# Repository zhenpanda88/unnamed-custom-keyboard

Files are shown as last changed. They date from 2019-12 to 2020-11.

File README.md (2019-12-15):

# untitled-keyboard-project
Unnamed custom mechanical keyboard project. I might finish this one day. It'll probably be a split layout. But eh...

Project Roadmap:
- V.0: Simple layout prototype for minimal functionality and software testing (probably 40%-size amount of keys)
- V.1: Ergonomic form layout and bigger layout (60%+ or 40% with different layers)
- V.2+: Bluetooth support, different layouts, on board LED display, backlighting (stretch goal, I doubt I will get this far lol)

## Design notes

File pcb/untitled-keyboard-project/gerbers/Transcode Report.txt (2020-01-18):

   ---- Transcoding 'C:\Users\White\AppData\Local\Temp\untitled-keyboard-project gerbers_importZIP\untitled-keyboard-project-F_Paste.gtp' ----   Thu Jan 02 16:57:49 2020

D10   --> D100
D12   --> D101
-----------------------------------------------------------------

   ---- Transcoding 'C:\Users\White\AppData\Local\Temp\untitled-keyboard-project gerbers_importZIP\untitled-keyboard-project-F_Cu.gtl' ----   Thu Jan 02 16:57:49 2020

D10   --> D102
D11   --> D103
D13   --> D104
D14   --> D105
D15   --> D106
D16   --> D107
D17   --> D108
-----------------------------------------------------------------

   ---- Transcoding 'C:\Users\White\AppData\Local\Temp\untitled-keyboard-project gerbers_importZIP\untitled-keyboard-project-Edge_Cuts.gml' ----   Thu Jan 02 16:57:49 2020

D10   --> D109
-----------------------------------------------------------------

   ---- Transcoding 'C:\Users\White\AppData\Local\Temp\untitled-keyboard-project gerbers_importZIP\untitled-keyboard-project-B_Cu.gbl' ----   Thu Jan 02 16:57:49 2020

D10   --> D110
D11   --> D111
D12   --> D112
D14   --> D113
D15   --> D114
D16   --> D115
D17   --> D116
-----------------------------------------------------------------

   ---- Transcoding 'C:\Users\White\AppData\Local\Temp\untitled-keyboard-project gerbers_importZIP\untitled-keyboard-project-B_Paste.gbp' ----   Thu Jan 02 16:57:49 2020

D11   --> D117
-----------------------------------------------------------------

   ---- Transcoding 'C:\Users\White\AppData\Local\Temp\untitled-keyboard-project gerbers_importZIP\untitled-keyboard-project-B_SilkS.gbo' ----   Thu Jan 02 16:57:49 2020

D10   --> D118
D11   --> D119
-----------------------------------------------------------------

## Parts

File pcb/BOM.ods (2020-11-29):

Ref | Component | Source | Ordered
U1 | ATmega32U4 | https://www.digikey.com/product-detail/en/microchip-technology/ATMEGA32U4RC-AU/ATMEGA32U4RC-AU-ND/2507982 | Y
J1 | MiniUSB | https://www.digikey.com/product-detail/en/edac-inc/690-005-299-043/151-1206-1-ND/4312192 | Y
J2 | 3.5mm TRRS Conn | https://www.amazon.com/Female-Connector-Stereo-Headphone-PJ320E/dp/B07SC79NWH | Y
C1, C2 | 18pF | https://www.digikey.com/product-detail/en/yageo/CC0805JRNPO9BN180/311-1102-1-ND/303012 | Y
C3 | 4.7pF | https://www.digikey.com/product-detail/en/kemet/C0805C479D5GACTU/399-9252-1-ND/3522770 | Y
C4, C5, C6, C7 | 0.1uF | https://www.digikey.com/product-detail/en/kemet/C0805C104Z5VACTU/399-1177-1-ND/411452 | Y
C8 | 1uF | https://www.digikey.com/product-detail/en/kemet/C0805C105Z4VACTU/399-8011-1-ND/3471734 | Y
R1, R2 | 10kOhm | https://www.digikey.com/product-detail/en/yageo/RC0805FR-0710KL/311-10.0KCRCT-ND/730482 | Y
R3, R4 | 22Ohm | https://www.digikey.com/product-detail/en/te-connectivity-passive-product/CRGCQ0805J22R/A130124CT-ND/8577956 | Y
SW1 | Reset Push Button | https://www.digikey.com/product-detail/en/e-switch/TL3342F160QG-TR/EG2531CT-ND/379004 | Y
X1 | Crystal 16MHz | https://www.digikey.com/product-detail/en/epson/FA-238-16.0000MB-C3/SER3686CT-ND/2403459 | Y
D1-24 | Diode | https://www.digikey.com/product-detail/en/taiwan-semiconductor-corporation/TS4148C-RZG/TS4148CRZGCT-ND/7359812 | Y

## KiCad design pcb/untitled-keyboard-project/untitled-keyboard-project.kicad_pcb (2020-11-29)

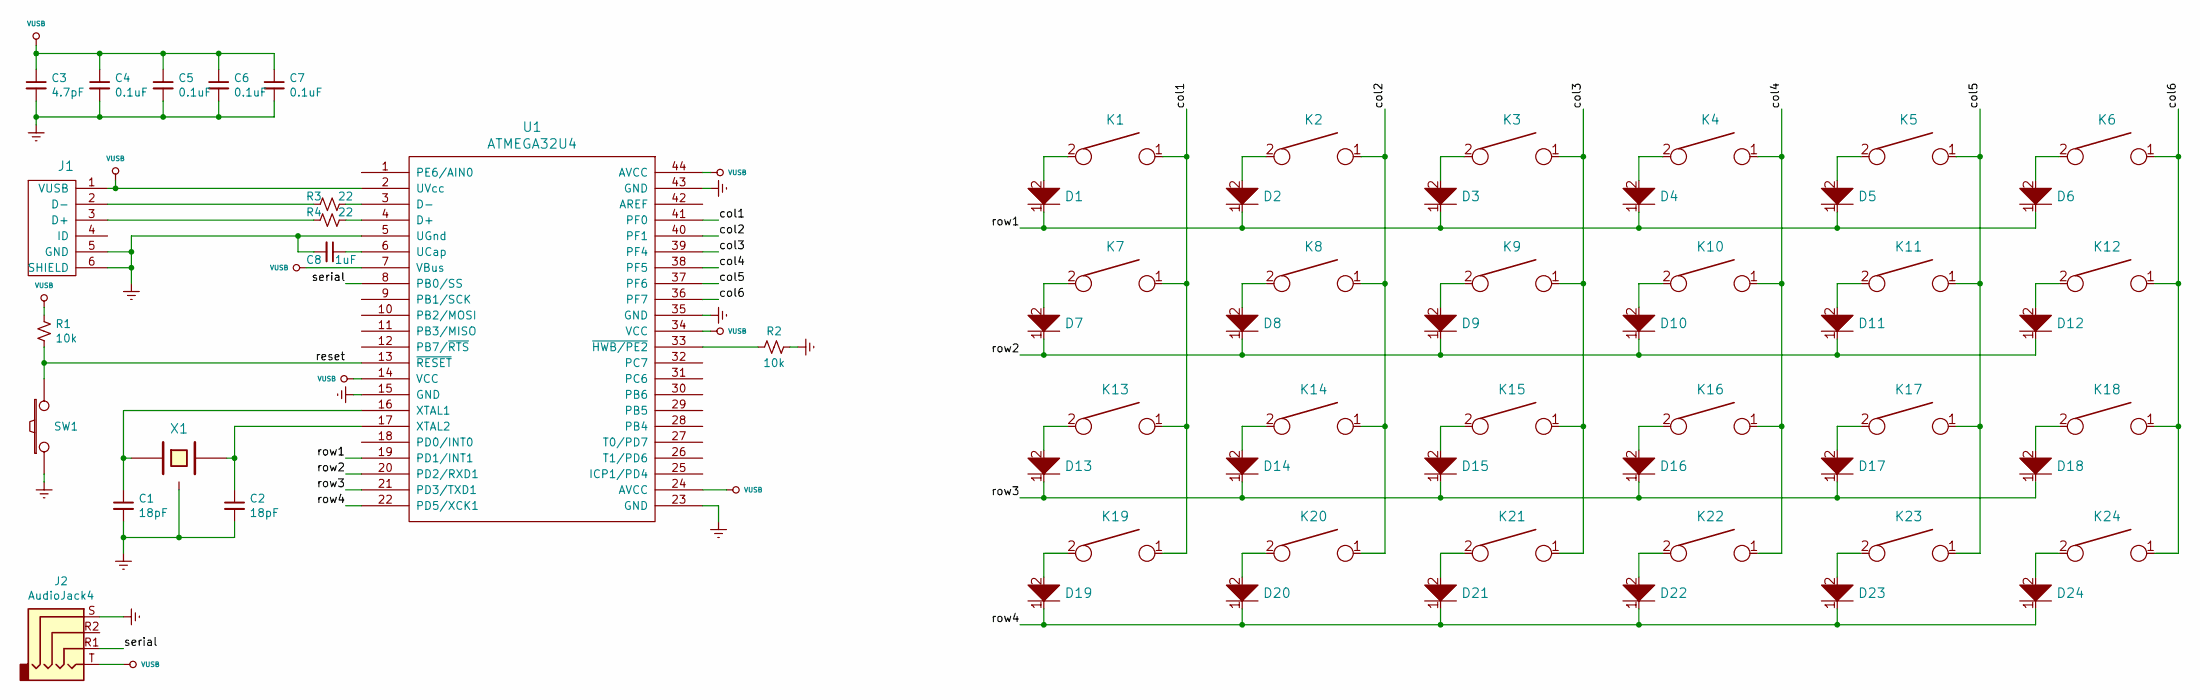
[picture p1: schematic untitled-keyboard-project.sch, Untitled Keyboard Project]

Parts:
C1, C2: 18pF; C_0805_2012Metric
C3: 4.7pF; C_0805_2012Metric
C4, C5, C6, C7: 0.1uF; C_0805_2012Metric
C8: 1uF; C_0805_2012Metric
D1, D2, D3, D4, D5, D6, D7, D8, D9, D10, D11, D12, D13, D14, D15, D16, D17, D18, D19, D20, D21, D22, D23, D24: D; D_0603_1608Metric
J1: USB_mini_micro_B; USB_Micro-B_Molex-105017-0001
J2: AudioJack4; Jack_3.5mm_PJ320E_Horizontal
K1, K2, K3, K4, K5, K6, K7, K8, K9, K10, K11, K12, K13, K14, K15, K16, K17, K18, K19, K20, K21, K22, K23, K24: KEYSW; SW_Cherry_MX_1.00u_PCB
R1, R2: 10k; R_0805_2012Metric
R3, R4: 22; R_0805_2012Metric
SW1: SW_PUSH; SW_SPST_TL3342
U1: ATMEGA32U4; TQFP-44_10x10mm_P0.8mm
X1: XTAL_GND; Crystal_SMD_TXC_7M-4Pin_3.2x2.5mm

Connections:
/col1: K1.1, K7.1, K13.1, K19.1, U1.41 (PF0)
/col2: K2.1, K8.1, K14.1, K20.1, U1.40 (PF1)
/col3: K3.1, K9.1, K15.1, K21.1, U1.39 (PF4)
/col4: K4.1, K10.1, K16.1, K22.1, U1.38 (PF5)
/col5: K5.1, K11.1, K17.1, K23.1, U1.37 (PF6)
/col6: K6.1, K12.1, K18.1, K24.1, U1.36 (PF7)
/reset: R1.1, SW1.2, U1.13 (~RESET)
/row1: D1.1, D2.1, D3.1, D4.1, D5.1, D6.1, U1.19 (PD1/INT1)
/row2: D7.1, D8.1, D9.1, D10.1, D11.1, D12.1, U1.20 (PD2/RXD1)
/row3: D13.1, D14.1, D15.1, D16.1, D17.1, D18.1, U1.21 (PD3/TXD1)
/row4: D19.1, D20.1, D21.1, D22.1, D23.1, D24.1, U1.22 (PD5/XCK1)
/serial: J2.R1, U1.8 (PB0/SS)
GNDREF: C1.2, C2.2, C3.2, C4.2, C5.2, C6.2, C7.2, C8.2, J1.5 (GND), J1.6 (SHIELD), J2.S, R2.2, SW1.1, U1.5 (UGnd), U1.15 (GND), U1.23 (GND), U1.35 (GND), U1.43 (GND), X1.2, X1.4
unnamed: C1.1, U1.16 (XTAL1), X1.1
unnamed: C2.1, U1.17 (XTAL2), X1.3
unnamed: C8.1, U1.6 (UCap)
unnamed: D1.2, K1.2
unnamed: D2.2, K2.2
unnamed: D3.2, K3.2
unnamed: D4.2, K4.2
unnamed: D5.2, K5.2
unnamed: D6.2, K6.2
unnamed: D7.2, K7.2
unnamed: D8.2, K8.2
unnamed: D9.2, K9.2
unnamed: D10.2, K10.2
unnamed: D11.2, K11.2
unnamed: D12.2, K12.2
unnamed: D13.2, K13.2
unnamed: D14.2, K14.2
unnamed: D15.2, K15.2
unnamed: D16.2, K16.2
unnamed: D17.2, K17.2
unnamed: D18.2, K18.2
unnamed: D19.2, K19.2
unnamed: D20.2, K20.2
unnamed: D21.2, K21.2
unnamed: D22.2, K22.2
unnamed: D23.2, K23.2
unnamed: D24.2, K24.2
unnamed: J1.2 (D-), R3.1
unnamed: J1.3 (D+), R4.1
unnamed: R2.1, U1.33 (~HWB/PE2)
unnamed: R3.2, U1.3 (D-)
unnamed: R4.2, U1.4 (D+)
VUSB: C3.1, C4.1, C5.1, C6.1, C7.1, J1.1 (VUSB), J2.T, R1.2, U1.2 (UVcc), U1.7 (VBus), U1.14 (VCC), U1.24 (AVCC), U1.34 (VCC), U1.44 (AVCC)

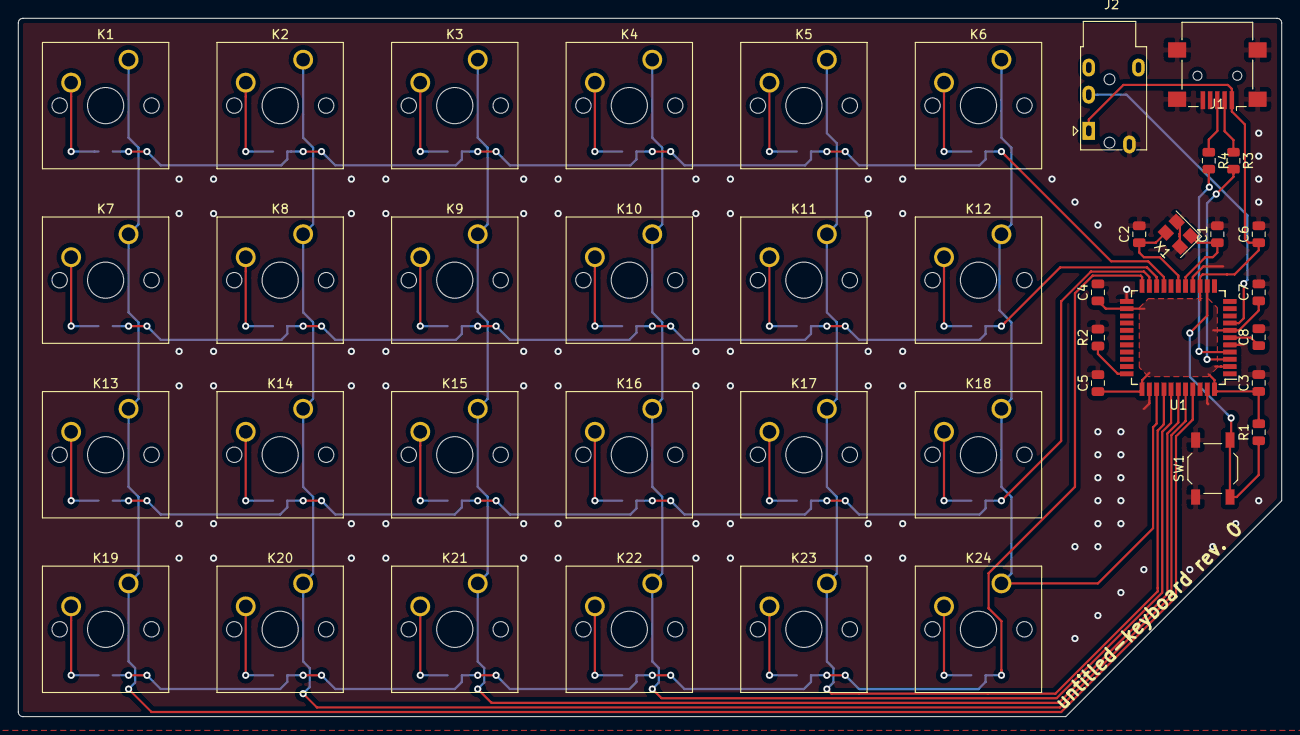
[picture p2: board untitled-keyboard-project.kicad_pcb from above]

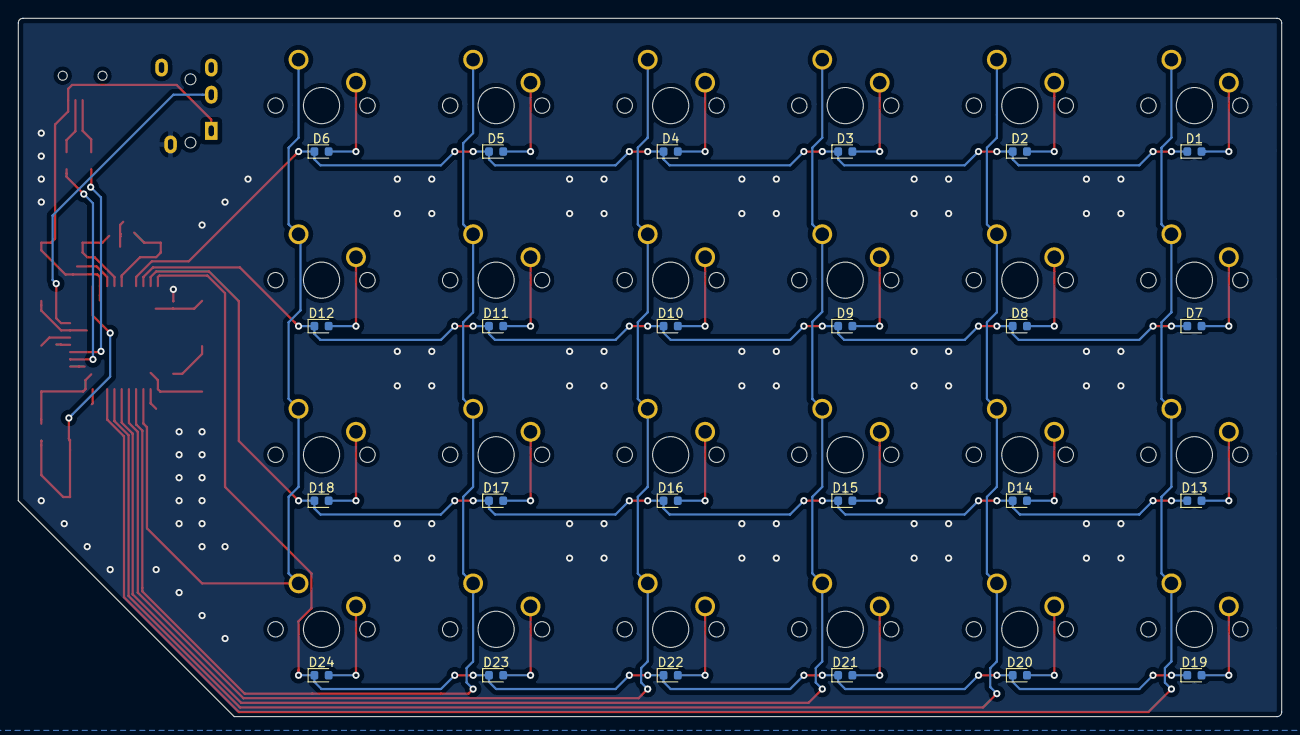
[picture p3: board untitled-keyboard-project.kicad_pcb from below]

Board: 2 copper layers, 139.7 x 77.2 mm, 65 parts (24 on the bottom side), 46 nets.

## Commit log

2019-12-12 Created KiCAD Project
    Created KiCAD project workspace (schematic and pcb).
    [unnamed-keyboard-project.kicad_pcb, unnamed-keyboard-project.sch]
2019-12-12 Update 12/11/19 23:46
    Added microprocessor and peripherals to schematic. Added empty BOM excel sheet.
    [BOM.ods, unnamed-keyboard-project.sch]
2019-12-12 Update 12/12/19 00:23
    Renamed KiCAD project to "Untitled Keyboard Project" and created a left and a right side schematic.
    [unnamed-keyboard-project.sch, untitled-keyboard-project-left.sch, untitled-keyboard-project-right.sch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]
2019-12-12 Update 12/12/19 13:58
    Updated README and BOM
    [BOM.ods]
2019-12-15 Added switches to right side PCB schematic
2019-12-18 Update 12/18/19 00:36
    Fixed net labels and assigned footprints to schematic symbols.
    [untitled-keyboard-project-right.sch]
2019-12-23 Update 12/23/19 00:05
    Reorganized KiCAD project. Created PCB file and started laying out components.
    [untitled-keyboard-project-left.sch, untitled-keyboard-project.sch]
2020-01-02 Finished layout for Rev 0 board
    [BOM.ods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]
2020-01-02 Updated Gerbers
    [untitled-keyboard-project-B_Cu.gbl, untitled-keyboard-project-B_Mask.gbs, untitled-keyboard-project-B_Paste.gbp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]
2020-11-29 Update 11/28/2020
    Capacitor Value Change
    File Cleanup
    [BOM.ods, untitled-keyboard-project.kicad_pcb, untitled-keyboard-project.sch]
